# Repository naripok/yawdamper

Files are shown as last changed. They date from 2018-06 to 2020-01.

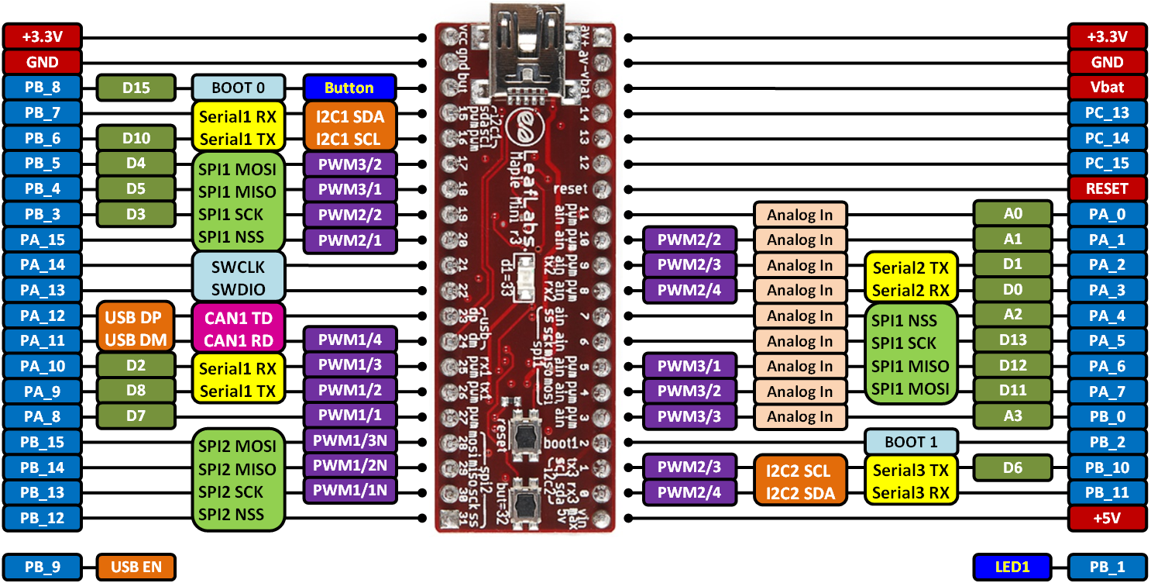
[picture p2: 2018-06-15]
assets/maplemini_pinout01.png

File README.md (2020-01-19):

# Yawdamper module for light experimental aircrafts

## DESCRIPTION:

This project uses a stm32f103c8, mpu6050 and ssd1306 as a yawdamper module for
light experimental aircraft applications.

This program is distributed under MIT license.  
It is an experimental module.   
**USE AT YOUR OWN RISK**

## PINMAP 
  
OLED
    PA4  -> RES  
    PA5  -> SCK  
    PA7  -> SDA  
    PB0  -> DC  
    PA6  -> CS  
  
BUTTONS
    PB13 -> MODE
    PB14 -> PLUS  
    PB15 -> MINUS    

SENSOR  
    PB12 -> INT  
    PB7  -> SDA  
    PB6  -> SCL  
    GND  -> GND  
    3.3  -> VCC  

SERVO  
    PA8  -> PWM  

CONTROLLER OUTPUT CONNECTOR  
    PIN1  ->  
    PIN2  ->  
    PIN3  ->  
    PIN4  ->  
    PIN5  -> SERVO GND  
    PIN6  ->  
    PIN7  ->  
    PIN8  ->  
    PIN9  -> GND  
    PIN10 -> PA8 -> PWM  
    PIN11 -> PB11  
    PIN12 -> PB10  
    PIN13 -> PB3  
    PIN14 ->  
    PIN15 -> 12V  

SERVO CONNECTOR  
    PIN1 -> VCC  
    PIN3 -> PWM  
    PIN9 -> GND  

### TODO:
    Gain auto tune

## Compiling

install libraries and hardware on ~/Arduino
install arduino-cli

> arduino-cli core install arduino:samd
> arduino-cli core install STM32:stm32

> arduino-cli compile --fqbn STM32:STM32F1:genericSTM32F103C yawdamper/master

## Uploading

install dfu-util

> dfup yawdamper/master/master.stm32.stm32f1.genericstm32f103c.bin

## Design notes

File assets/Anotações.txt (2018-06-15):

Alterações Headers:
	Leitura pura do sensor na MPU6050.cpp (trocou de uint16 pra int16)
	Frequência de operação do servo no servo.cpp (período de 20ms pra 20/6 ms)
	
Programas:
	Para utilzar os outros eixos basta trocar o ponteiro (usedAxis)
	entretando deve-se comentar adequadamente a escrita(calibração) e leitura (cfg)

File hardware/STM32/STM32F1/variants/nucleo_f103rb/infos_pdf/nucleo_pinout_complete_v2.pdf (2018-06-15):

## left

## side

remapable | default function | Arduino | Name Pin | | Pin Name | | Arduino | default function | remapable
| TX Serial2* | D31 | PC10 | 1 | 2 | PC11 | D44 | RX Serial2*
| SDIO_CK | | PC12 | 3 | 4 | PD2 | D30 | TIM3_ETR
| | | VDD | 5 | 6 | E5V
| | | Boot0 | 7 | 8 | GND | GND
| | | NC | 9 | 10 | NC | NC
| | | NC | 11 | 12 | IORef | IoRef
| SWDIO | D41 | PA13 | 13 | 14 | RST | RST
| SWCKL | D42 | PA14 | 15 | 16 | 3,3V | 3,3V
TIM2_CH1_ETR/SPI1_SS | JTDI | D43 | PA15 | 17 | 18 | 5V | 5V
| | | GND | 19 | 20 | GND | GND
| I2C1_SDA/TIM4_CH2 | D22 | PB7 | 21 | 22 | GND | GND
| User Button | D27 | PC13 | 23 | 24 | Vin | Vin
| 32khz! | D28 | PC14 | 25 | 26 | NC
| 32khz! | D29 | PC15 | 27 | 28 | PA0 | A0/D16 | ADC12_IN0/TIM2_CH1_ETR
| OSC** | | PD0 | 29 | 30 | PA1 | A1/D17 | ADC12_IN1/TIM2_CH2
| OSC** | | PD1 | 31 | 32 | PA4 | A2/D18 | SPI1_SS/ADC12_IN4
| | | Vbat | 33 | 34 | PB0 | A3/D19 | ADC12_IN8/TIM3_CH3 | TIM1_CH2N
| ADC12_IN12 | D23 | PC2 | 35 | 36 | PC1 | A4/D20 | ADC12_IN11
| ADC12_IN13 | D24 | PC3 | 37 | 38 | PC0 | A5/D21 | ADC12_IN10

## right

## side

remapable | default function | Arduino | Name Pin | | Pin | Name | Arduino | default function | remapable
TIM3_CH4 | | D40 | PC9 | 1 | 2 | PC8 | D39 | | TIM3_CH3
I2C1_SCL | TIM4_CH3 | D15 | PB8 | 3 | 4 | PC6 | D38 | | TIM3_CH1
I2C1_SDA | TIM4_CH4 | D14 | PB9 | 5 | 6 | PC5 | D26 | ADC12_IN15
| | VDD | AVDD | 7 | 8 | U5V
| | GND | GND | 9 | 10 | NC
| LED/SPI1_SCK/ADC12_IN5 | D13 | PA5 | 11 | 12 | PA12 | D45 | USBDP TIM1_ETR
TIM1_BKIN | SPI1_MISO/ADC12_IN6/TIM3_CH1 | D12 | PA6 | 13 | 14 | PA11 | D33 | TIM1_CH4
TIM1_CH1N | SPI1_MOSI/ADC12_IN7/TIM3_CH2 | D11 | PA7 | 15 | 16 | PB12 | D34 | SPI2_SS/I2C2_SMBAl/TIM1_BKIN
| I2C1_SCL/TIM4_CH1 | D10 | PB6 | 17 | 18 | PB11 | | I2C2_SDA | TIM2_CH4

TIM3_CH2 | | D9 | PC7 | 19 | 20 | GND
| TX Serial/TIM1_CH2 | D8 | PA9 | 21 | 22 | PB2 | D46 | Boot1
| TIM1_CH1/MCO | D7 | PA8 | 23 | 24 | PB1 | D32 | ADC12_IN9/TIM3_CH4 | TIM1_CH3N
TIM2_CH3 | I2C2_SCL | D6 | PB10 | 25 | 26 | PB15 | D37 | SPI2_MOSI/TIM1_CH3N
TIM3_CH1/SPI1_MISO | | D5 | PB4 | 27 | 28 | PB14 | D36 | SPI2_MISO/TIM1_CH2N
/SPI1_MOSI TIM3_CH2 | I2C1_SMBAl | D4 | PB5 | 29 | 30 | PB13 | D35 | SPI2_SCK/TIM1_CH1N
/SPI1_SCK TIM2_CH2 | RX Serial /SWO** | D3 | PB3 | 31 | 32 | AGND
| RX Serial/TIM1_CH3 | D2 | PA10 | 33 | 34 | PC4 | D25 | ADC12_IN14
use desolder jumper for | TX Serial1**/ADC12_IN2/TIM2_CH3 | D1 | PA2 | 35 | 36 | NC
desolder jumper for use | RX Serial1**/ADC12_IN3/TIM2_CH4 | D0 | PA3 | 37 | 38 | NC

*SW

remapped | 5V
Tolerant | Arduino
Header

### **solder

mod | | Arduino
pin

NR
!

### not

in

use | Dxx | save
to

use?

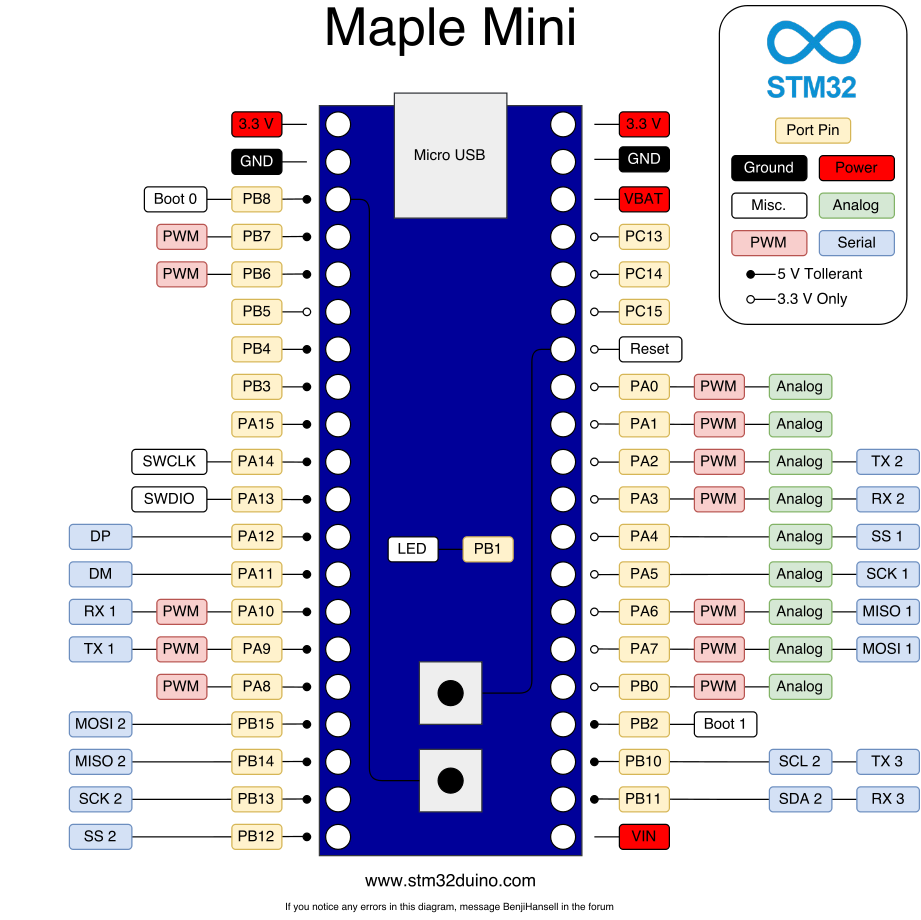
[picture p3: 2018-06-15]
assets/921px-Maple_Mini_Pinout.svg.png

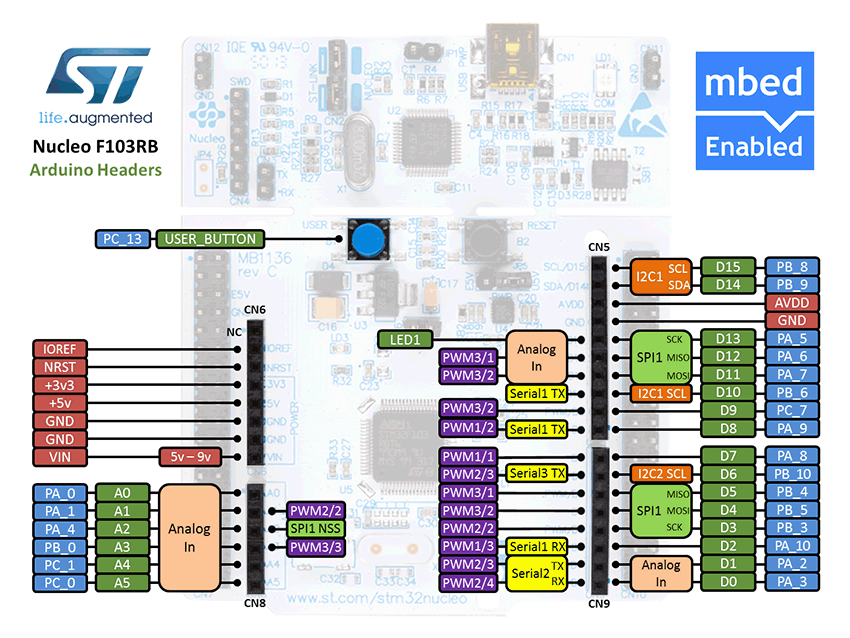
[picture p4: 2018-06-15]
hardware/STM32/STM32F1/variants/nucleo_f103rb/infos_pdf/st-nucleo-f103rb-arduino_headers.png

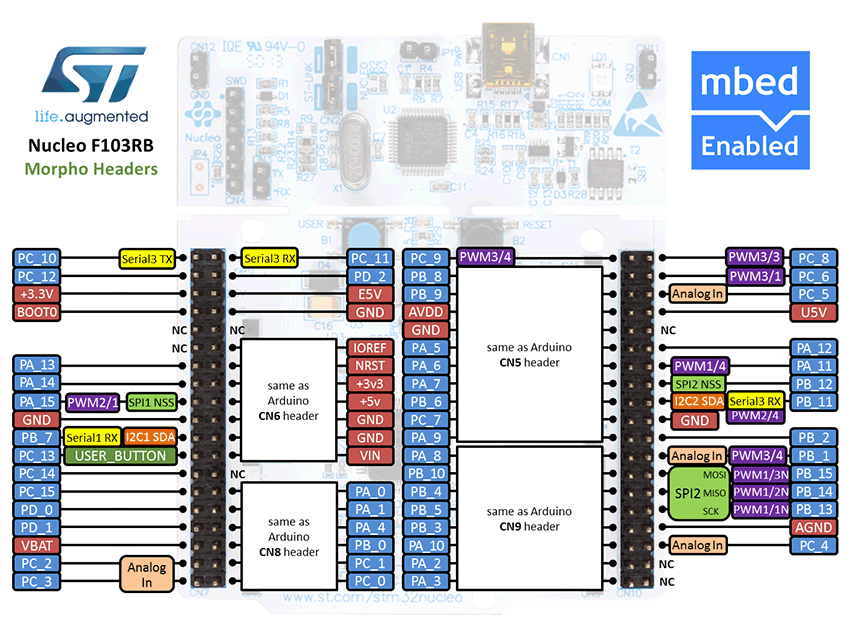
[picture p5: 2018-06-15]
hardware/STM32/STM32F1/variants/nucleo_f103rb/infos_pdf/st-nucleo-f103rb-morpho-headers.png

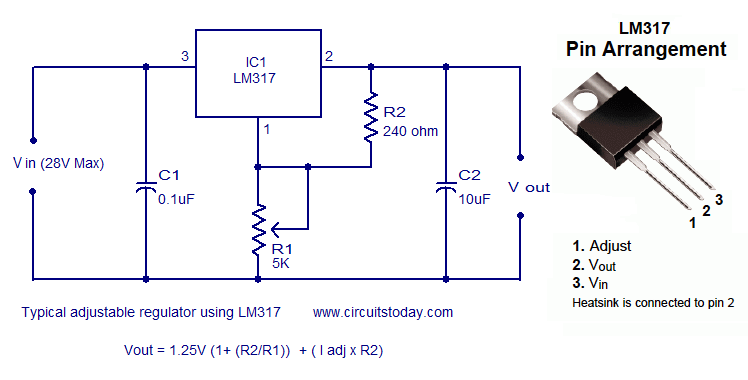
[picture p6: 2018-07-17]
assets/lm317.png

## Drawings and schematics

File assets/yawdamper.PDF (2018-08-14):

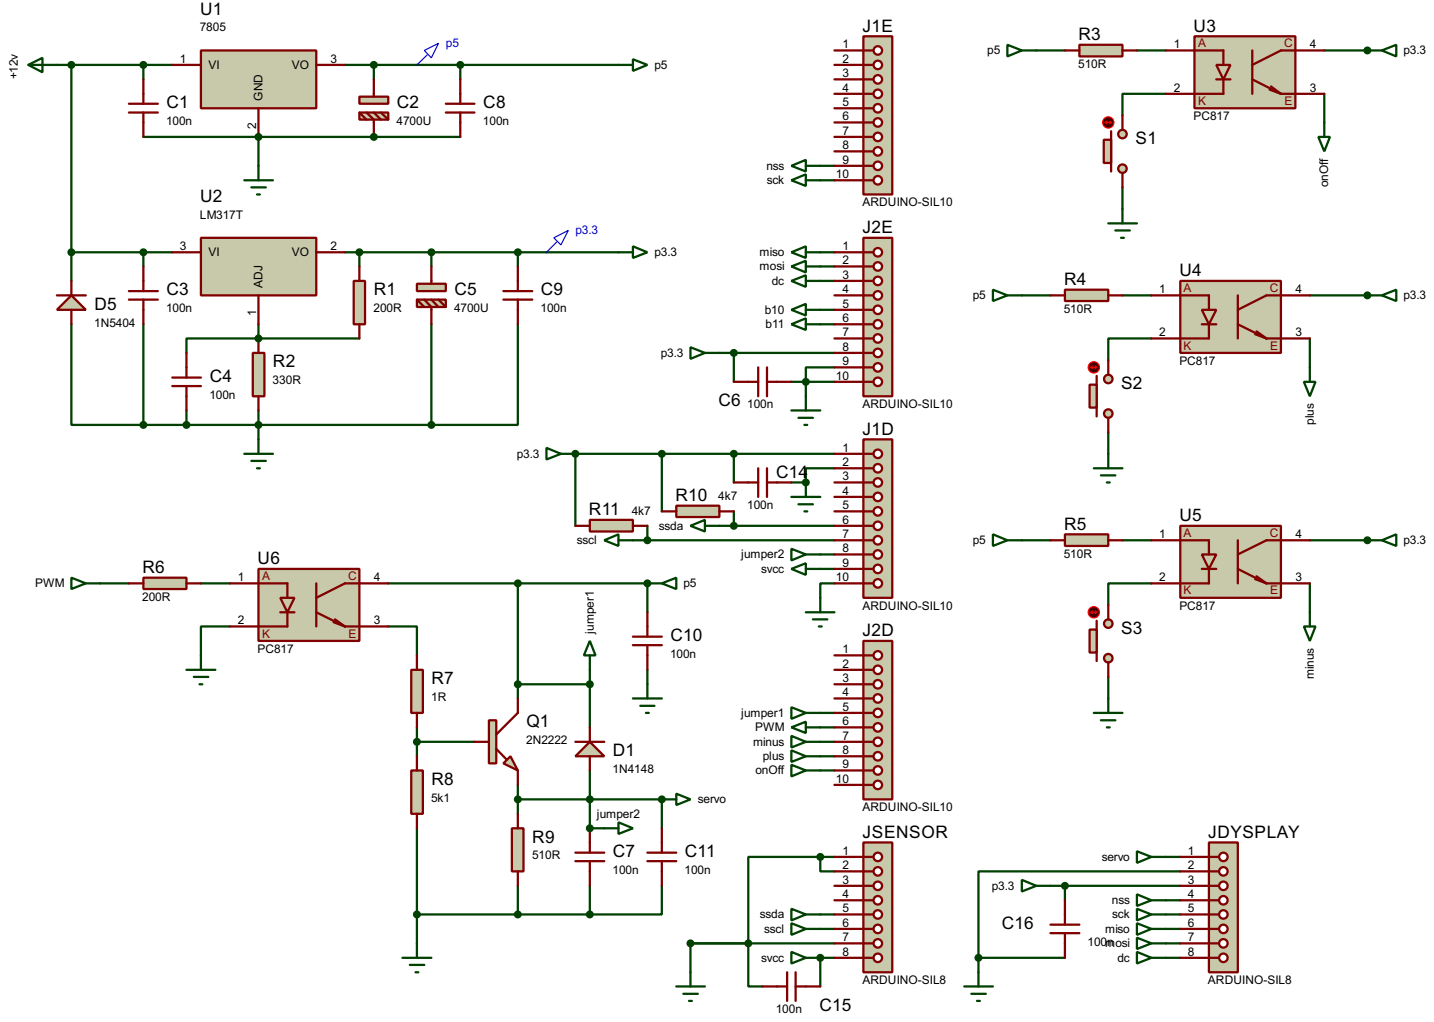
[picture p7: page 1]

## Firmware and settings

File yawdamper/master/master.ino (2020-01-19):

/******************************************************************************
 * The MIT License
 *
 * Copyright (c) 2010 Perry Hung.
 * Copyright (c) 2012 LeafLabs, LLC.
 *
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
 * THE SOFTWARE IS PROVIDED "AS IS", WITHOUT WARRANTY OF ANY KIND,
 * EXPRESS OR IMPLIED, INCLUDING BUT NOT LIMITED TO THE WARRANTIES OF
 * MERCHANTABILITY, FITNESS FOR A PARTICULAR PURPOSE AND
 * NONINFRINGEMENT. IN NO EVENT SHALL THE AUTHORS OR COPYRIGHT HOLDERS
 * BE LIABLE FOR ANY CLAIM, DAMAGES OR OTHER LIABILITY, WHETHER IN AN
 * ACTION OF CONTRACT, TORT OR OTHERWISE, ARISING FROM, OUT OF OR IN
 * CONNECTION WITH THE SOFTWARE OR THE USE OR OTHER DEALINGS IN THE
 * SOFTWARE.
 *****************************************************************************/

/**
 * @file yawdamper/yawdamper.ino
 * @author Fernando Canteruccio <tau@megali.com>
 * @brief Yawdamper device module.
 *
 */

/**
 * Tau, 15/06/2018
 * Yawdamper master module
 *
 * TODO:
 *      UI
 *
 * DESCRIPTION:
 *
 * This project uses a stm32f103c8, mpu6050 and ssd1306 as a yawdamper module for
 * light experimental aircraft applications.
 *
 * ## PINMAP ###########################################################################################################
 *
 *  OLED TODO
 *      PA4  -> RES
 *      PA5  -> SCK
 *      PA6  -> CS
 *      PA7  -> SDA
 *      PB0  -> DC
 *
 *  BUTTONS
 *      PB13 -> MODE
 *      PB14 -> PLUS
 *      PB15 -> MINUS
 *
 *  SENSOR
 *      PB12 -> INT
 *      PB7  -> SDA
 *      PB6  -> SCL
 *      GND  -> GND
 *      3.3  -> VCC
 *
 *  SERVO
 *      PA8  -> PWM
 *
 *  CONTROLLER OUTPUT CONNECTOR
 *      PIN1  ->
 *      PIN2  ->
 *      PIN3  ->
 *      PIN4  ->
 *      PIN5  -> SERVO GND
 *      PIN6  ->
 *      PIN7  ->
 *      PIN8  ->
 *      PIN9  -> GND
 *      PIN10 -> PA8 -> PWM
 *      PIN11 ->
 *      PIN12 ->
 *      PIN13 ->
 *      PIN14 ->
 *      PIN15 -> 12V
 *
 *  SERVO CONNECTOR
 *      PIN1 -> VCC
 *      PIN3 -> PWM
 *      PIN9 -> GND
 *
 */

/*
 * PID coef
 *
 * KP = 2.7
 * KI = 2.4
 * KD = 1.2
 *
 * ALPHA = 30
 */

#include <Arduino.h>
#include <Adafruit_SSD1306.h>
#include <EEPROM.h>
#include <MPU6050.h>
#include <PID_v1.h>
#include <Filters.h>
#include <Servo.h>
#include <Wire.h>
#include <libmaple/iwdg.h>
#include <HardwareTimer.h>

#include <libmaple/i2c.h>
#include <libmaple/systick.h>

#include <libmaple/rcc.h>
#include <libmaple/util.h>
#include <libmaple/scb.h>


/**
 * #####################################################################################################################
 * ###                                                                                                               ###
 * ###                                              MEMORY MANAGEMENT                                                ###
 * ###                                                                                                               ###
 * #####################################################################################################################
 */

/* #define DEBUG */
#define PROBE_PIN               PB12
#define DEBUG_LEVEL DEBUG_NONE
//#define I2C_DEBUG

/** Time ###############################################################################################################
 *
 * #####################################################################################################################
 */
#ifdef DEBUG
unsigned int loopFreq;
#endif
const unsigned long loopTime = 1999;
volatile unsigned int i = 1;

// Watchdog
#define IWDG_NUM                210 //210
#define IWDG_PRESCALER          IWDG_PRE_256


/** SENSOR #############################################################################################################
 *
 * #####################################################################################################################
 */
// Sensor macros
// #define SENSOR_SCL           PB6                  // m16
// #define SENSOR_SDA           PB7                  // m15
#define SENSOR_VCC              PB4
//#define INT_PIN
#define SDA                     PB7
#define SCL                     PB6
#define DLPF                    MPU6050_DLPF_6       // 5hz - 19ms delay

#define SENSOR_IWDG             13000
#define T                       Timer2
#define c                       2


// Sensor vars
const unsigned int SENSOR_MOD = 2;
const unsigned int CALIBRATION_SAMPLES = 10000;                // calibration mean n of samples
const float G = 9.80665;                             // gravity as written in the sensor header

float pitch = 0.0;                            // pitch measurement
float roll = 0.0;                             // roll measurement
float yaw = 0.0;                              // yaw measurement
float offsetPitch = 0.0;                          // offset after calibration
float offsetRoll = 0.0;                           // offset after calibration
float offsetYaw = 0.0;                            // offset after calibration
//
//float offsetGx;                             // offset after calibration
//float offsetGy;                             // offset after calibration
//float offsetGz;                             // offset after calibration

float gyroX = 0.0;
float gyroY = 0.0;
float gyroZ = 0.0;
float gyroThreshold = 0.0;

float alpha = 1.0;                          // exponential filter decay
float *usedAxis;                            // pointer to used axis
float *usedGAxis;                            // pointer to used axis

int axis = 0;                               // axis selection helper variable
int sensorReverse = 1;

volatile bool canRead = true;

// Sensor instances
Vector normA;                                        // Accelerometer vector
Vector normG;                                        // Gyro vector
MPU6050 mpu;

// Input filters
FilterOnePole accelPole1(LOWPASS, alpha * 2);
FilterOnePole accelPole2(LOWPASS, alpha * 3);
FilterOnePole accelPole3(LOWPASS, alpha * 4);
FilterOnePole gyroPole1(LOWPASS, alpha * 2);
FilterOnePole gyroPole2(LOWPASS, alpha * 3);
FilterOnePole gyroPole3(LOWPASS, alpha * 4);


/** PID ################################################################################################################
 *
 * #####################################################################################################################
 */

// Time step vars
const double PID_FREQ = 250; //166.6666;
const double TIME_STEP = 1 / PID_FREQ;
const double ACCEL_MULTIPLIER = 10;
const double GYRO_MULTIPLIER = 50;
const double KD_MULTIPLIER = 0.3;

double gyroDot = 0.0;
double input = 0.0;
double output = 0.0;
double setpoint = 0.0;
double gain = 0.0;
double gainG = 0.0;
double gyroT = 0.0;
double KP = 0.0;                            // proportional
double KI = 0.0;                            // integral
double KD = 0.0;                            // derivative
double sensitivity = 0.0;
double nl = 0.0;

int pidMode = 0;                            // 0 -> DIRECT, 1 -> REVERSE

bool pidOn = false;                         // true if in automatic mode, false if in manual

// PID instance
PID pid(&input, &output, &setpoint, gain * KP, gain * KI, gain * KD_MULTIPLIER * KD * (1 + sensitivity), pidMode);


/** DISPLAY ############################################################################################################
 *
 * #####################################################################################################################
 */
// Display macros
#define OLED_DC                 PB0  // 7
#define OLED_CS                 PA6  // 7
#define OLED_RESET              PA4  // 8
/* #define OLED_CS                 SS  // 5 */
/* #define OLED_RESET              MISO  // 8 */

// Display vars
const int DISPLAY_MOD = 3;
long time;

int j = 0; // activity counter
const int MSG_DELAY = 20;
int puMsg = 0;
int e1 = 0;
int e2 = 0;
int e3 = 0;
int e4 = 0;
int e5 = 0;
int e6 = 0;
int pidCalib = 0;

// Display instance
Adafruit_SSD1306 display(OLED_DC, OLED_RESET, OLED_CS);


/** SERVO ##############################################################################################################
 *
 * #####################################################################################################################
 */
// Servo macros
#define SERVO_PIN               PA8

// Servo vars
const int SERVO_MOD = 3;
const int SERVO_MIN_DEG = 0;
const int SERVO_MAX_DEG = 180;
int pos = 90;                               // position in degrees
float trimValue = 0;                        // value of output when pid is on manual mode

// Servo instance
Servo servo;


/** INTERFACE ##########################################################################################################
 *
 * #####################################################################################################################
 */
// Buttons macros
#define ON_OFF_PIN              PB13
#define PLUS_PIN                PB14
#define MINUS_PIN               PB15

// Buttons vars
const int B_MOD = 5;
bool onOff;
bool pidOnOff;
bool minusB;
bool plusB;
bool prevOnOff;
bool prevPidOnOff;
bool prevCalibration;
bool prevB;
bool prevPB;
unsigned long pressTime;
unsigned long pidPressTime;
unsigned long releaseTime = -1500; // initialized as -1500 so that printTuning is not called at the first loops
const unsigned long calibrationTime = 1000;
const unsigned long debounceDelay = 300;
bool powerUser = false;

/** EEPROM #############################################################################################################
 *
 * #####################################################################################################################
 */
// EEPROM macros.
#define GYROT_ADDRESS           0x1F
#define SENS_ADDRESS            0x1E
#define NL_ADDRESS              0x1D
#define GAING_ADDRESS           0x1C
#define AXIS_ADDRESS            0x1B
#define SENSOR_REVERSE_ADDRESS  0x1A
#define ALPHA_ADDRESS           0x19
#define PID_MODE_ADDRESS        0x18
#define KP_ADDRESS              0x17
#define KI_ADDRESS              0x16
#define KD_ADDRESS              0x15
#define GAIN_ADDRESS            0x14
#define TRIM_ADDRESS            0x13
#define OFFSET_PITCH_ADDRESS    0x12
#define OFFSET_ROLL_ADDRESS     0x11
#define OFFSET_YAW_ADDRESS      0x10

// EEPORM instances
uint16 dataWrite;
uint16 dataRead;
uint16 eepromStatus;


/** END MEMORY MANAGEMENT ##############################################################################################
 */


/**
 * #####################################################################################################################
 * ###                                                                                                               ###
 * ###                                                  PROCEDURES                                                   ###
 * ###                                                                                                               ###
 * #####################################################################################################################
 */

// FAULT HANDLING ######################################################################################################
#ifdef DEBUG
#define LED_PIN                 PC13

void cfgProbes(void) {
    pinMode(PROBE_PIN, OUTPUT);
    digitalWrite(PROBE_PIN, LOW);

}


void flipP1(void) {
    digitalWrite(PROBE_PIN, !digitalRead(PROBE_PIN));
}
#endif

// SENSOR PROCEDURES ###################################################################################################
void readSensor(void) {
    /**
     * Reads values from the sensor registers
     */

    // Read sensor
    normA = mpu.readNormalizeAccel();
    normG = mpu.readNormalizeGyro();

    // Apply exponential filtering to chosen axis
    switch (axis) {
        case 0:
            pitch = sensorReverse * (
                    accelPole3.input(
                    accelPole2.input(
                    accelPole1.input(
                            normA.YAxis
                    ))) - offsetPitch);
            gyroZ = sensorReverse * gyroPole3.input(gyroPole2.input(gyroPole1.input(normG.ZAxis)));
            break;
        case 1:
            roll = sensorReverse * (
                    accelPole3.input(
                    accelPole2.input(
                    accelPole1.input(
                            normA.XAxis
                    ))) - offsetRoll);
            gyroZ = sensorReverse * gyroPole3.input(gyroPole2.input(gyroPole1.input(normG.ZAxis)));
            break;
        case 2:
            yaw = sensorReverse * (
                    accelPole3.input(
                    accelPole2.input(
                    accelPole1.input(
                            normA.ZAxis
                    ))) - offsetYaw);
            gyroX = sensorReverse * gyroPole3.input(gyroPole2.input(gyroPole1.input(normG.XAxis)));
            break;
        default:
            break;
    }
}


void calibrateAccelerometer(void) {
    /* Reads a "calibrationSamples" amount of values from the sensor
     saving the mean to the offset variables.
    */

    iwdg_feed();
    feedSensorWtdg();

    display.clearDisplay();
    display.setTextSize(1);
    display.setTextColor(WHITE);
    display.setCursor(16, 12);
    display.println("Calibrando Sensor");
    display.display();

    Vector normC;

    offsetPitch = 0;
    offsetRoll = 0;
    offsetYaw = 0;

    double offset1 = 0;
    double offset2 = 0;
    double offset3 = 0;

    int k = 0;
    while (k <= CALIBRATION_SAMPLES) {
        iwdg_feed();
        feedSensorWtdg();
        delay(1);
        k++;
        normC = mpu.readNormalizeAccel();

        offset1 += normC.YAxis;
        offset2 += normC.XAxis;
        offset3 += normC.ZAxis;

        if (k % 10 == 0) {
            display.drawRect(16, 24, 97, 20, WHITE);
            display.fillRect(16, 24, (1 + (k / double(CALIBRATION_SAMPLES)) * 96), 20, WHITE);
            display.display();
        }
    }

    offsetPitch = offset1 / CALIBRATION_SAMPLES;
    offsetRoll = offset2 / CALIBRATION_SAMPLES;
    offsetYaw = offset3 / CALIBRATION_SAMPLES;

    writeEEPROM(OFFSET_PITCH_ADDRESS, offsetPitch);
    writeEEPROM(OFFSET_ROLL_ADDRESS, offsetRoll);
    writeEEPROM(OFFSET_YAW_ADDRESS, offsetYaw);
}


void recoverSensor(void) {
    // Power cycle MPU for fresh start
    digitalWrite(SENSOR_VCC, LOW);

    i2c_disable(I2C1);
    i2c_master_enable(I2C1, I2C_BUS_RESET);

    // Turn sensor off and wait for 100ms while feeding the watchdogs
    for (int i = 0; i < 100; i++) {
        feedSensorWtdg();
        iwdg_feed();
        delay(1);
    }

    digitalWrite(SENSOR_VCC, HIGH);

    for (int i = 0; i < 100; i++) {
        feedSensorWtdg();
        iwdg_feed();
        delay(1);
    }

    mpu.writeRegister8(0x24, 0b00001001);                                   // 400khz clock

    // Initialize MPU6050
    while(!mpu.recover(MPU6050_SCALE_250DPS, MPU6050_RANGE_2G)) {
        feedSensorWtdg();
        iwdg_feed();
        // While not initialized, display error msg
        display.clearDisplay();
        display.setTextSize(1);
        display.setTextColor(WHITE);
        display.setCursor(12, 25);
        display.println("FALHA NO SENSOR");
        display.display();

    };

    // Configure mpu
    mpu.setDLPFMode(DLPF);                                                  // Set low pass filter band
    mpu.setTempEnabled(false);                                              // disable temperature sensor
//    mpu.setAccelPowerOnDelay(MPU6050_DELAY_1MS);                          // delay start for compatibility issues
    mpu.writeRegister8(0x23, 0b00000000);                                   // Disable FIFO queues

    mpu.setThreshold(gyroT / 10);

    for (int i = 0; i < 10; i++) {
        feedSensorWtdg();
        iwdg_feed();
        delay(1);
    }

    // update fail counter
//    writeEEPROM(FAIL_ADDRESS, failCount++);
}


void cfgSensor(void) {
    /**
     * Configures MPU6050.
     */

    // Feed watchdog
    iwdg_feed();

    // Configure controller VCC pin as output
    pinMode(SENSOR_VCC, OUTPUT);
    digitalWrite(SENSOR_VCC, HIGH);

    // Initialize MPU6050
    while(!mpu.begin(MPU6050_SCALE_250DPS, MPU6050_RANGE_2G)) {
        iwdg_feed();
        // While not initialized, display error msg
        display.clearDisplay();
        display.setTextSize(1);
        display.setTextColor(WHITE);
        display.setCursor(12, 25);
        display.println("FALHA NO SENSOR");
        display.display();
    };

    // Configure mpu
    mpu.writeRegister8(0x24, 0b00001001);                                   // 400khz clock
    mpu.writeRegister8(MPU6050_REG_GYRO_CONFIG, 0b00000000);                // Gyro self test disable
    mpu.setDLPFMode(DLPF);                                                  // Set low pass filter band
    mpu.setTempEnabled(false);                                              // disable temperature sensor
    mpu.writeRegister8(0x23, 0b00000000);                                   // Disable FIFO queues
//    mpu.setAccelPowerOnDelay(MPU6050_DELAY_1MS);                          // delay start for compatibility issues
//    mpu.writeRegister8(0x37, 0b00010000);                                 // Interruption pin config
//    mpu.writeRegister8(0x38, 0b00000001);                                 // Interruption config

    // Read offsets from EEPROM
    offsetPitch = readEEPROM(OFFSET_PITCH_ADDRESS);
    offsetRoll = readEEPROM(OFFSET_ROLL_ADDRESS);
    offsetYaw = readEEPROM(OFFSET_YAW_ADDRESS);
    // Read used axis from EEPROM
    axis = readEEPROM(AXIS_ADDRESS);
    // Read all the other configs
    gyroT = readEEPROM(GYROT_ADDRESS);


    // Update pointer to used axis
    if (axis == 0) {
        usedAxis = &pitch;
        usedGAxis = &gyroZ;
    } else if (axis == 1) {
        usedAxis = &roll;
        usedGAxis = &gyroZ;
    } else if (axis == 2) {
        usedAxis = &yaw;
        usedGAxis = &gyroX;
    }

    // Feed watchdog
    iwdg_feed();

    displayMsg("Calibrando Gyro...");
    mpu.setThreshold(gyroT / 10);
    mpu.calibrateGyro(200);
}


// TIMER PROCEDURES ####################################################################################################
void resetSensor(void) {
    canRead = false;
}


void feedSensorWtdg(void) {
    T.refresh();
}


void cfgSensorWtdg(void) {
    T.setPeriod(SENSOR_IWDG);
    T.attachInterrupt(c, resetSensor);
}


// PID procedures ######################################################################################################
static inline float sgn(float val) {
    if (val < 0) return -1;
    if (val==0) return 0;
    return 1;
}


void computePID(void) {
    // Calculates the output of the PID
    input = ACCEL_MULTIPLIER * (sgn(*usedAxis) * pow(abs(*usedAxis), 1 + nl));

    if (pid.Compute()) {
        // Add gyro differential control
        output = constrain(output - gain * gainG * GYRO_MULTIPLIER * (*usedGAxis - gyroDot), -G, G);

        // save data for the next loop
        gyroDot = *usedGAxis;
//        prevOutput = output;

        // Converts the output to a value in degree and drive servo
        servo.write(convert_output(output));
    }
}


void cfgPID(void) {
    /* Configures the PID.
    */
    setpoint = 0;
    pid.SetOutputLimits(-G, G);
    pid.SetSampleTime(1000 * TIME_STEP);

    sensorReverse = readEEPROM(SENSOR_REVERSE_ADDRESS);
    alpha = readEEPROM(ALPHA_ADDRESS);
    trimValue = readEEPROM(TRIM_ADDRESS);
    gain = readEEPROM(GAIN_ADDRESS);
    KP = readEEPROM(KP_ADDRESS);
    KI = readEEPROM(KI_ADDRESS);
    KD = readEEPROM(KD_ADDRESS);
    pidMode = readEEPROM(PID_MODE_ADDRESS);
    gainG = readEEPROM(GAING_ADDRESS);
    nl = readEEPROM(NL_ADDRESS);
    sensitivity = readEEPROM(SENS_ADDRESS);
    output = trimValue;

    accelPole1.setFrequency(alpha * 2);
    accelPole2.setFrequency(alpha * 3);
    accelPole3.setFrequency(alpha * 4);
    gyroPole1.setFrequency(alpha * 2);
    gyroPole2.setFrequency(alpha * 3);
    gyroPole3.setFrequency(alpha * 4);

    pid.SetControllerDirection(pidMode);
    pid.SetTunings(gain * KP, gain * KI, gain * KD_MULTIPLIER * KD * (1 + sensitivity));
}


// SERVO PROCEDURES ####################################################################################################
int convert_output(float output) {
    pos = ((output + G) * (SERVO_MAX_DEG - SERVO_MIN_DEG) / (2 * G)) + SERVO_MIN_DEG;
    return pos;
}


void cfgServo(void) {
    /* Configures the servo.
    */
    servo.attach(SERVO_PIN, 1100, 2200, 0, 180);
    servo.write(convert_output(trimValue));
}
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
void loop() {
//#ifdef DEBUG
//    flipP1();
//#endif
    // Keep initial loop time
    time = micros();

    // Increase counter
    i++;

    if (!canRead) {

    }

    if (i % SENSOR_MOD == 0) {
        if (canRead) {
            // Feed the dogs...
            iwdg_feed();
            feedSensorWtdg();

            readSensor();

            computePID();

        } else {
            recoverSensor();

            i = 1;
            canRead = true;
        }

    } else if (i % DISPLAY_MOD == 0) {
        refreshScreen();

    } else if (i % B_MOD == 0) {
        processInterface();
        i = 1;
    }

    // Wait for loop to complete
    while ((micros() - time) < loopTime) {
        if (I2C1->state == I2C_STATE_ERROR) {
            canRead = false;
            i = 1;
            break;
        }
    }
#ifdef DEBUG
    loopFreq = 1000000 / (micros() - time);
#endif
#ifdef DEBUG
    flipP1();
#endif
} // END LOOP

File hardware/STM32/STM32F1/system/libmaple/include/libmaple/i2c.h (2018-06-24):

/******************************************************************************
 * The MIT License
 *
 * Copyright (c) 2010 Perry Hung.
 * Copyright (c) 2012 LeafLabs, LLC.
 *
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
 * THE SOFTWARE IS PROVIDED "AS IS", WITHOUT WARRANTY OF ANY KIND,
 * EXPRESS OR IMPLIED, INCLUDING BUT NOT LIMITED TO THE WARRANTIES OF
 * MERCHANTABILITY, FITNESS FOR A PARTICULAR PURPOSE AND
 * NONINFRINGEMENT. IN NO EVENT SHALL THE AUTHORS OR COPYRIGHT HOLDERS
 * BE LIABLE FOR ANY CLAIM, DAMAGES OR OTHER LIABILITY, WHETHER IN AN
 * ACTION OF CONTRACT, TORT OR OTHERWISE, ARISING FROM, OUT OF OR IN
 * CONNECTION WITH THE SOFTWARE OR THE USE OR OTHER DEALINGS IN THE
 * SOFTWARE.
 *****************************************************************************/

/**
 * @file libmaple/include/libmaple/i2c.h
 * @brief Inter-Integrated Circuit (I2C) peripheral support
 *
 * Currently master-only. Usage notes:
 *
 * - Enable an I2C device with i2c_master_enable().
 * - Initialize an array of struct i2c_msg to suit the bus
 *   transactions (reads/writes) you wish to perform.
 * - Call i2c_master_xfer() to do the work.
 */

#ifndef _LIBMAPLE_I2C_H_
#define _LIBMAPLE_I2C_H_

#ifdef __cplusplus
extern "C" {
#endif

/*
 * Series header must provide:
 *
 * - uint32 _i2c_bus_clk(i2c_dev*): Clock frequency of dev's bus, in
 *   MHz. (This is for internal use only).
 *
 * - (optional) _I2C_HAVE_IRQ_FIXUP: Leave undefined, or define to 1.
 *   This is for internal use only. It's a hack to work around a
 *   silicon bug related to I2C IRQ pre-emption on some targets. If 1,
 *   the series header must also declare and implement a routine with
 *   this signature (it may also be provided as a macro):
 *
 *       void _i2c_irq_priority_fixup(i2c_dev*)
 *
 *   This will be called by i2c_enable_irq() before actually enabling
 *   I2C interrupts.
 *
 * - Reg. map base pointers, device pointer declarations.
 */

 /* Roger clark. Replaced with line below #include <series/i2c.h>*/
#include "stm32f1/include/series/i2c.h"
#include <libmaple/i2c_common.h>

#include <libmaple/libmaple_types.h>
#include <libmaple/rcc.h>
#include <libmaple/nvic.h>
#include <libmaple/gpio.h>

/** I2C register map type */
typedef struct i2c_reg_map {
    __io uint32 CR1;            /**< Control register 1 */
    __io uint32 CR2;            /**< Control register 2 */
    __io uint32 OAR1;           /**< Own address register 1 */
    __io uint32 OAR2;           /**< Own address register 2 */
    __io uint32 DR;             /**< Data register */
    __io uint32 SR1;            /**< Status register 1 */
    __io uint32 SR2;            /**< Status register 2 */
    __io uint32 CCR;            /**< Clock control register */
    __io uint32 TRISE;          /**< TRISE (rise time) register */
} i2c_reg_map;

/**
 * @brief I2C message type
 */
typedef struct i2c_msg {
    uint16 addr;                /**< Address */

#define I2C_MSG_READ            0x1
#define I2C_MSG_10BIT_ADDR      0x2
    /**
     * Bitwise OR of:
     * - I2C_MSG_READ (write is default)
     * - I2C_MSG_10BIT_ADDR (7-bit is default) */
    uint16 flags;

    uint16 length;              /**< Message length */
    uint16 xferred;             /**< Messages transferred */
    uint8 *data;                /**< Data */
} i2c_msg;

/*
 * Register bit definitions
 */

/* Control register 1 */

#define I2C_CR1_SWRST           (1U << 15)    // Software reset
#define I2C_CR1_ALERT           (1U << 13)    // SMBus alert
#define I2C_CR1_PEC             (1U << 12)    // Packet error checking
#define I2C_CR1_POS             (1U << 11)    // Acknowledge/PEC position
#define I2C_CR1_ACK             (1U << 10)    // Acknowledge enable
#define I2C_CR1_STOP            (1U << 9)     // Stop generation
#define I2C_CR1_START           (1U << 8)     // Start generation
#define I2C_CR1_NOSTRETCH       (1U << 7)     // Clock stretching disable
#define I2C_CR1_ENGC            (1U << 6)     // General call enable
#define I2C_CR1_ENPEC           (1U << 5)     // PEC enable
#define I2C_CR1_ENARP           (1U << 4)     // ARP enable
#define I2C_CR1_SMBTYPE         (1U << 3)     // SMBus type
#define I2C_CR1_SMBTYPE_DEVICE  (0U << 3)     //     SMBus type: device
#define I2C_CR1_SMBTYPE_HOST    (1U << 3)     //     SMBus type: host
#define I2C_CR1_SMBUS           (1U << 1)     // SMBus mode
#define I2C_CR1_SMBUS_I2C       (0U << 1)     //     SMBus mode: I2C
#define I2C_CR1_SMBUS_SMBUS     (1U << 1)     //     SMBus mode: SMBus
#define I2C_CR1_PE              (1U << 0)     // Peripheral Enable

/* Control register 2 */

#define I2C_CR2_LAST            (1U << 12)    // DMA last transfer
#define I2C_CR2_DMAEN           (1U << 11)    // DMA requests enable
#define I2C_CR2_ITBUFEN         (1U << 10)    // Buffer interrupt enable
#define I2C_CR2_ITEVTEN         (1U << 9)     // Event interupt enable
#define I2C_CR2_ITERREN         (1U << 8)     // Error interupt enable
#define I2C_CR2_FREQ            0x3F          // Peripheral input frequency

/* Own address register 1 */

#define I2C_OAR1_ADDMODE        (1U << 15)    // Addressing mode
#define I2C_OAR1_ADDMODE_7_BIT  (0U << 15)    //     Addressing mode: 7-bit
#define I2C_OAR1_ADDMODE_10_BIT (1U << 15)    //     Addressing mode: 10-bit
#define I2C_OAR1_ADD            0x3FF         // Interface address

/* Own address register 2 */

#define I2C_OAR2_ADD2           0xFE          // Interface address
#define I2C_OAR2_ENDUAL         1U            // Dual addressing mode enable

/* Status register 1 */

#define I2C_SR1_SMBALERT        (1U << 15)    // SMBus alert
#define I2C_SR1_TIMEOUT         (1U << 14)    // Timeout or Tlow error
#define I2C_SR1_PECERR          (1U << 12)    // PEC Error in reception
#define I2C_SR1_OVR             (1U << 11)    // Overrun/underrun
#define I2C_SR1_AF              (1U << 10)    // Acknowledge failure
#define I2C_SR1_ARLO            (1U << 9)     // Arbitration lost
#define I2C_SR1_BERR            (1U << 8)     // Bus error
#define I2C_SR1_TXE             (1U << 7)     // Data register empty
#define I2C_SR1_RXNE            (1U << 6)     // Data register not empty
#define I2C_SR1_STOPF           (1U << 4)     // Stop detection
#define I2C_SR1_ADD10           (1U << 3)     // 10-bit header sent
#define I2C_SR1_BTF             (1U << 2)     // Byte transfer finished
#define I2C_SR1_ADDR            (1U << 1)     // Address sent/matched
#define I2C_SR1_SB              (1U << 0)     // Start bit

/* Status register 2 */
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

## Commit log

2018-06-15 spi flags
2018-06-15 spi com done
2018-06-18 gyro gain
2018-06-18 servo max min
2018-06-19 stable timing 60hz
2018-06-19 no gyro calib
2018-06-19 stable 60hz
2018-06-21 i2c recovery
2018-06-21 i2c back
2018-06-24 i2c recovery, memory dump
2018-06-29 gyro calib
2018-06-29 servo init first
2018-07-01 mpu reset time (fixed i2c hang)
    [i2c.c, master.ino]
2018-07-01 i2c flag on while
2018-07-15 fix pid direction init, mpu filter
    [master.ino]
2018-07-17 gyro kp only
2018-07-17 gyro scale, button function
2018-07-17 reversed trim, const filters
    [master.ino]
2018-07-25 pid freq
2018-07-26 cascading filters
2018-07-26 3 cascading filters
2018-07-30 power user
2018-07-30 calibration samples, gain g positive
2018-07-31 pcb, manual
    [pcb_template.kicad_pcb, pcb_template.sch]
2018-08-11 yawdamper y001 schema
2018-08-15 servo freq, clock gain
2018-08-17 servo pwm freq
2020-01-18 rm filters link
2020-01-18 add filters library
2020-01-19 spi pins, compilation - uploads instructions
